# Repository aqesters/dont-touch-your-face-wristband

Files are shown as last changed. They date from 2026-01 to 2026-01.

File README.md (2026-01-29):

# dont-touch-your-face-wristband
A wristband that vibrates when the wearer tries to touch their face

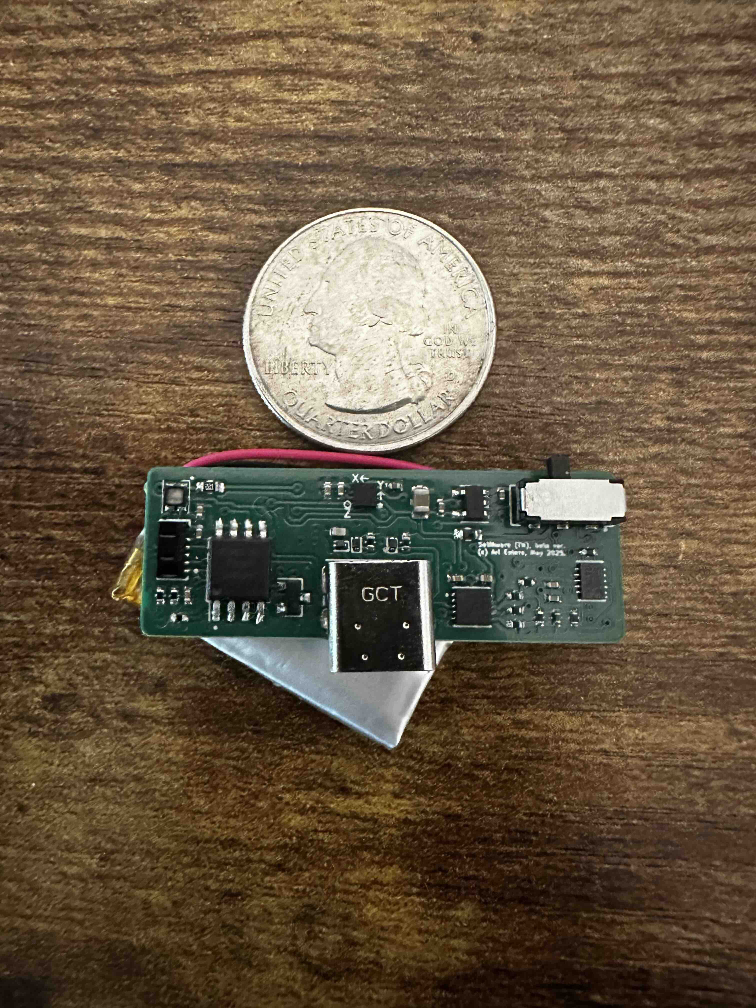
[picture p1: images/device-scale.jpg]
Assembled device


## System overview
First of all, the device must be worn on the inside of the wrist, facing towards the body when one's arm is by their side. 

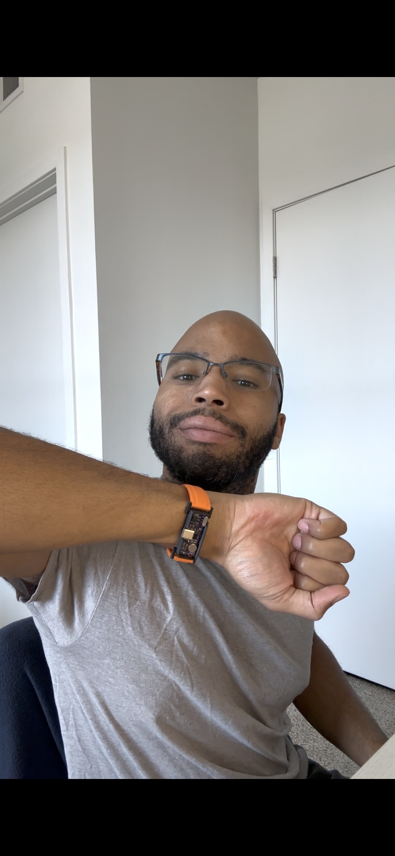
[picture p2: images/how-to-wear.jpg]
How to wear


The wristband functions by using two sensors: an accelerometer to measure arm position, and an IR optical sensor to measure proximity. The workflow is described below.
- The microcontroller remains in Sleep mode to conserve power until the arm is raised.
- Once the arm is raised - which is determined by an accelerometer threshold - the accelerometer wakes the microcontroller (MCU) via pin interrupt.
- The MCU remains in Active mode while the arm is raised. In Active mode, the MCU continuously polls the proximity sensor.
- If the proximity reading surpasses a certain threshold, the MCU triggers the vibration motor to alert the wearer.

Note that an alert will not be sent to the wearer unless both the arm is raised (accelerometer threshold) and the hand is close to the face (proximity threshold). This increases the likelihood that the wearer receives a vibration alert only if their hand is near their neck face.

## Cover glass for proximity sensor
In the assembly, the proximity sensor is purposely placed near the edge of the board. At this position, the sensor can detect proximity both above and beside the PCB. If using a cover glass, the following conditions must be met for best performance:
1. The cover glass must be made of IR-transparent material
2. The proximity sensor threshold may need to be increased, as cover glass will reflect some IR back to the sensor 
3. The cover glass should be curved such that the proximity sensor is sensitive to detection both above and near the edge of the PCB (see example)

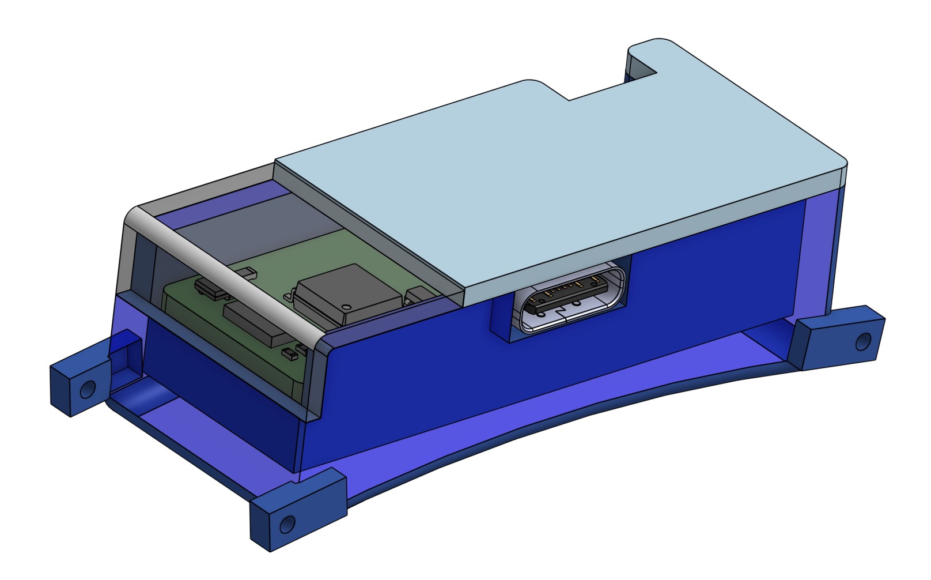
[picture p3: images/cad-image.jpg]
3D CAD rendering of assembled device


Note that this implementation for proximity sensing is **PATENT PENDING**.

## Enclosure
The enclosure has been designed to be 3D-printable using PLA and a 0.2 mm nozzle. The design is compatible with off-the-shelf 18 mm wrist straps (see link).

[Amazon link to wrist straps](https://www.amazon.com/dp/B0C1RQ1HML)

The enclosure consists of a "bottom" (which the PCB sits in) and a "lid" (which is glued to the "bottom" to cover the PCB). The enclosure was designed using Onshape. The STEP files are included in `enclosure/`, and the Onshape design file can be accessed at the link below.

[Link to Onshape CAD file](https://cad.onshape.com/documents/f453aeea43687b5a9c082ca3/w/8d4d5c0042ac79ddd7b31543/e/8a52f216663301647b5c429d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)

## Electronics
The Kicad design files, Gerber files, component datasheets, and bill of materials (BOM) are included in `electronics/`. The BOM includes components that can be assembled onto the board by PCB manufacturers. Not included in the BOM are the lithium polymer battery and the vibration motor. Links for those are provided below.

### Battery
The battery used in the initial version is a lithium polymer battery with a capacity of 110 mAh and dimensions of 28mm x 12mm x 4mm. The battery leads must be soldered to pads on the PCB.

The link points to a battery from LiPol battery, product number LP401228. Note that this is a foreign provider, and foreign shipping can be expensive. *It might be possible to find a **more convenient** LiPo battery vendor that can provide batteries with similar dimensions.*

[LiPo battery link](https://www.lithium-polymer-battery.net/8mah-200mah-3-7v-lithium-polymer-battery/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)

### Vibration motor
The motor used in the initial version is a brushed DC haptic motor from Vybronics. These can be purchased from Digikey. The motor leads must be soldered to pads on the PCB.

[Vibration motor link](https://www.digikey.com/en/products/detail/vybronics-inc/VCLP0820B004L/10285889)

## Firmware
The initial version uses an ATtiny85 microcontroller, and the firmware is written and compiled using the Arduino IDE with AtTinyCore board configuration. The Arduino file can be found in `firmware/`.

There are custom drivers for the IR proximity sensor and the battery gauge (present on board, but not yet used by firmware). These drivers are required by the MCU firmware to communicate with these components. These can be found in `firmware/libraries/` and must be included in the Arduino libraries path on the machine compiling the firmware (typical path is `~/Arduino/libraries`).

## Known issues
### No easy way to upload firmware
In-system programming (ISP) is not trivial for the ATtiny85 MCU due to the limited number of pins. The pins used for ISP are also used for I2C communication by the MCU. This is a limitation of the MCU itself, which is limited in its number of pins and features.

----- Potential solution -----

Implement BOTH of the following:
- Add series resistors (470 Ohms) on the PB0 and PB2 pins of the MCU.
- Add pads shorted to MCU Pins *VCC*, *GND*, *PB0*, *PB1*, *PB2*, and *PB5* to the board layout. These pads can be used in an ISP layout to re-program the MCU in place.

### IR proximity sensor VCNL4020 is at End-Of-Life
Vishay Semiconductor no longer sells the VCNL4020 sensor included in this design. However, the VCNL4030X1 is supported and is very similar, though it uses a different footprint.

----- Potential solution -----

Replace VCNL4020 sensor with VCNL4030X1 sensor. Replace the VCNL4020 part with the VCNL4030X1 part in the Kicad schematic and layout (symbol and footprint files already included). Create a driver for VCNL4030X1 using the VCNL4020 driver (in `firmware/libraries/`) as a starting point. 

### Unclear assembly directions for entire part 
The assembly instructions could be clearer, including the best order of operations (e.g., first cut wires to this length for battery and motor, then solder motor, then solder battery, etc...). I will try to expand on assembly instructions in the future. In the meantime, feel free to reach out to me with any questions.

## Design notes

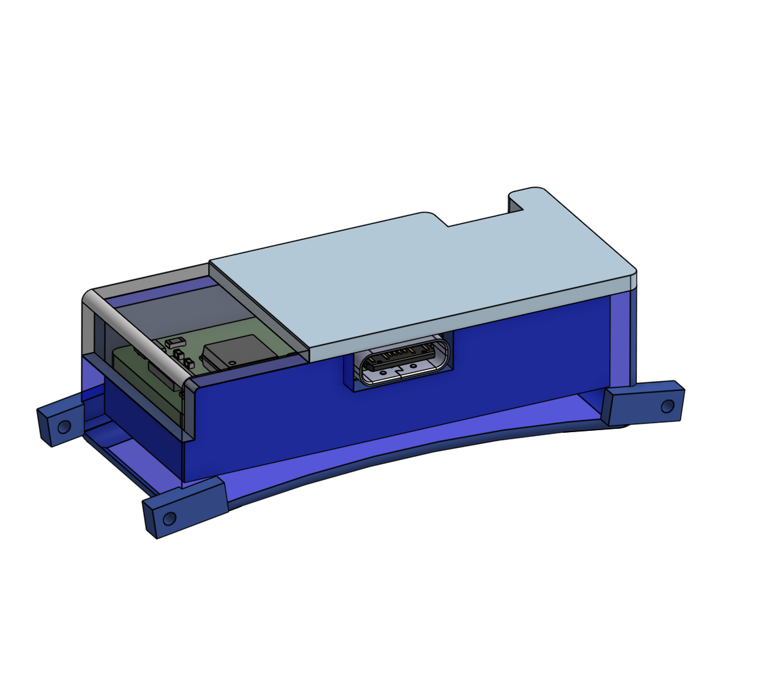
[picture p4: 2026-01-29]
images/cad-image-square.jpg

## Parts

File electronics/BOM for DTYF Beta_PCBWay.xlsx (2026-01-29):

 |  |  | Bill of Materials for DTYF Beta
Item # | *Designator | *Qty | Manufacturer | *Mfg Part # | Description / Value | *Package/Footprint | Type | Your Instructions / Notes
1 | C1, C3, C5, C6, C7, C8, C10, C11, C12 | 9 | Samsung Electro-Mechanics | CL05B104KP5NNNC | Unpolarized capacitor 100nF | 0402 | SMD
2 | C2, | 1 | Samsung Electro-Mechanics | CL05B224KO5NNNC | Unpolarized capacitor 220nF | 0402 | SMD
3 | C4, | 1 | Samsung Electro-Mechanics | CL05A105KO5NNNC | Unpolarized capacitor 1uF | 0402 | SMD
4 | C9, | 1 | Samsung Electro-Mechanics | CL05A475KQ5NRNC | Unpolarized capacitor 4.7 uF | 0402 | SMD
5 | C13, | 1 | Samsung Electro-Mechanics | CL05A106MQ5NUNC | Unpolarized capacitor 10uF | 0402 | SMD
6 | C14, | 1 | Samsung Electro-Mechanics | CL21A476MQYNNNE | Unpolarized capacitor 47 uF | 0805 | SMD
7 | D1, | 1 | Cree LED | CLMVC-FKA-CL1D1L71BB7C3C3 | RGB LED, anode/blue/green/red | PLCC4_2X2mm_CW | SMD | Pad 1 marked on PCB layout
8 | D2, | 1 | onsemi | ESD9B5.0ST5G | ESD protection diode, 5.0Vrwm | SOD-923 | SMD
9 | D3, D4, | 2 | onsemi | ESD9B3.3ST5G | ESD protection diode, 3.3Vrwm | SOD-923 | SMD
10 | J1, | 1 | GCT | USB4085-GF-A | USB-C receptacle connector USB4085 | GCT-USB4085 | Thru-hole
11 | J2, J3, | 2 | - | - | Custom SMD pads for customer use | - | DNI | DNI - No parts specified
12 | Q1, | 1 | onsemi | 2N7002 | 0.115A Id, 60V Vds, N-Channel MOSFET | SOT-23 | SMD
13 | R1, | 1 | YAGEO | RC0603FR-07220RL | Resistor 220 Ohms | 0603 | SMD
14 | R2, | 1 | Panasonic Electronic Components | ERJ-2BWFR050X | Current sense resistor 50 mOhms, 1% tolerance | 0402 | SMD | If replaced, tolerance must be 1% max
15 | R3, | 1 | Panasonic Electronic Components | ERJ-2RKF1001X | Resistor 1k | 0402 | SMD
16 | R4, R12, | 2 | Panasonic Electronic Components | ERJ-2RKF1004X | Resistor 1M | 0402 | SMD
17 | R5, | 1 | Panasonic Electronic Components | ERJ-2RKF1303X | Resistor 130k | 0402 | SMD
18 | R6, | 1 | Panasonic Electronic Components | ERA-2AEB9090X | Resistor 909 | 0402 | SMD
19 | R7, R9, R10, | 3 | Panasonic Electronic Components | ERJ-2GEJ472X | Resistor 4.7k | 0402 | SMD
20 | R8, | 1 | Panasonic Electronic Components | ERJ-3EKF22R0V | Resistor 22 | 0603 | SMD
21 | R11, | 1 | Panasonic Electronic Components | ERJ-2GEJ223X | Resistor 22k | 0402 | SMD
22 | R13, R14, | 2 | Panasonic Electronic Components | ERJ-2GEJ512X | Resistor 5.1k | 0402 | SMD
23 | SW1, | 1 | C&K | JS102011JAQN | Switch, single pole double throw (SPDT) | SW_SPDT_CK-JS102011JAQN | SMD | Pad 1 marked on PCB layout
24 | TH1, | 1 | Murata Electronics | NCU15XH103F6SRC | NTC 10k, temperature-dependent resistor | 0402 | SMD
25 | U1, | 1 | STMicroelectronics | LSM303AGRTR | IMU, accelerometer + magnetometer | LGA-12 | SMD | Pad 1 marked on PCB layout
26 | U2, | 1 | STMicroelectronics | STC3115AIQT | IC battery monitor | DFN-10 | SMD | Pad 1 marked on PCB layout
27 | U3, | 1 | Vishay Semiconductor | VCNL4020-GS08 | Optical sensor, IR and ambient | VDFN-10 | SMD | Pad 1 marked on PCB layout
28 | U4, | 1 | Microchip Technology | MCP73834-CNI/MF | IC single-cell battery control | DFN-10 | SMD | Pad 1 marked on PCB layout
29 | U5, | 1 | Microchip Technology | ATTINY85-20SU | AtTiny85 MCU, 8kB Flash, 512B SRAM, 512B EEPROM | SOIC-8 | DNI | DNI - I will program and install
30 | U6, | 1 | Diodes Incorporated | AP2112K-3.3TRG1 | 3.3V / 600mA LDO regulator with enable pin | SOT-25 | SMD | Pad 1 marked on PCB layout
 |  | 44
Need a quick and accurante quote? Need an efficient production? Please read SMT Ordering Necessary Files & Info in 1 minute. Thank you very much!
Click for Instructions on How to Create a BOM (https://www.pcbway.com/blog/PCB_Assembly/How_to_Build_a_BOM__Bill_Of_Materials_.html)

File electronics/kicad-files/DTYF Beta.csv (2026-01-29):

Source: | /Users/aesters/KiCad/DTYF Beta/DTYF Beta.sch
Date: | Tuesday, May 13, 2025 at 10:02:07 AM
Tool: | Eeschema (5.1.9-0-10_14)
Generator: | /private/var/folders/29/kllrrlc97vqc5shptfvqt_yr0000gn/T/AppTranslocation/2EDB60D3-1D7B-4026-A727-D76486822BE3/d/kicad.app/Contents/SharedSupport/plugins/bom_csv_grouped_by_value_with_fp.py
Component Count: | 44
Ref | Qnty | Value | Cmp name | Footprint | Description | Vendor
C1, C3, C5, C6, C7, C8, C10, C11, C12, | 9 | 100n | C | Capacitor_SMD:C_0402_1005Metric | Unpolarized capacitor
C2, | 1 | 220n | C | Capacitor_SMD:C_0402_1005Metric | Unpolarized capacitor
C4, | 1 | 1u | C | Capacitor_SMD:C_0402_1005Metric | Unpolarized capacitor
C9, | 1 | 4.7u | C | Capacitor_SMD:C_0402_1005Metric | Unpolarized capacitor
C13, | 1 | 10u | C | Capacitor_SMD:C_0402_1005Metric | Unpolarized capacitor
C14, | 1 | 47u | C | Capacitor_SMD:C_0805_2012Metric | Unpolarized capacitor
D1, | 1 | LED_ABGR | LED_ABGR | LED_SMD:LED_Cree-PLCC4_2x2mm_CW | RGB LED, anode/blue/green/red
D2, | 1 | ESD9B5.0ST5G | ESD9B5.0ST5G | Diode_SMD:D_SOD-923 | ESD protection diode, 5.0Vrwm, SOD-923
D3, D4, | 2 | ESD9B3.3ST5G | ESD9B3.3ST5G | Diode_SMD:D_SOD-923 | ESD protection diode, 3.3Vrwm, SOD-923
J1, | 1 | USB_C_Receptacle_GCT_USB4085 | USB_C_Receptacle_GCT_USB4085 | Connector_USB:USB_C_Receptacle_GCT_USB4085 | USB Full-Featured Type-C Receptacle connector
J2, J3, | 2 | Conn_01x02_Female | Conn_01x02_Female | 1_MyFootprints:SMD_Pads_X1_Y2_W3mm | Generic connector, single row, 01x02, script generated (kicad-library-utils/schlib/autogen/connector/)
Q1, | 1 | 2N7002 | 2N7002 | Package_TO_SOT_SMD:SOT-23 | 0.115A Id, 60V Vds, N-Channel MOSFET, SOT-23
R1, | 1 | 220 | R | Resistor_SMD:R_0603_1608Metric | Resistor
R2, | 1 | 50m | R | Resistor_SMD:R_0402_1005Metric | Resistor
R3, | 1 | 1k | R | Resistor_SMD:R_0402_1005Metric | Resistor
R4, R12, | 2 | 1M | R | Resistor_SMD:R_0402_1005Metric | Resistor
R5, | 1 | 130k | R | Resistor_SMD:R_0402_1005Metric | Resistor
R6, | 1 | 909 | R | Resistor_SMD:R_0402_1005Metric | Resistor
R7, R9, R10, | 3 | 4.7k | R | Resistor_SMD:R_0402_1005Metric | Resistor
R8, | 1 | 22 | R | Resistor_SMD:R_0603_1608Metric | Resistor
R11, | 1 | 22k | R | Resistor_SMD:R_0402_1005Metric | Resistor
R13, R14, | 2 | 5.1k | R | Resistor_SMD:R_0402_1005Metric | Resistor
SW1, | 1 | SW_SPDT | SW_SPDT | Button_Switch_SMD:SW_SPDT_CK-JS102011JAQN | Switch, single pole double throw
TH1, | 1 | 10k therm | Thermistor | Resistor_SMD:R_0402_1005Metric | Temperature dependent resistor
U1, | 1 | LSM303AGR | LSM303AGR-LSM303AGR | 1_MyFootprints:LSM303AGR
U2, | 1 | STC3115AIQT | STC3115AIQT | 1_MyFootprints:STC3115AIQT
U3, | 1 | VCNL4020-GS08 | VCNL4020-GS08-VCNL_Vishay | 1_MyFootprints:VCNL4020-GS08
U4, | 1 | MCP73834 | MCP73834 | 1_MyFootprints:MCP73834-CNI&slash_MF
U5, | 1 | ATtiny85-20SU | ATtiny85-20SU | Package_SO:SOIC-8_5.275x5.275mm_P1.27mm | 20MHz, 8kB Flash, 512B SRAM, 512B EEPROM, debugWIRE, SOIJ-8
U6, | 1 | AP2112K-3.3 | AP2112K-3.3 | Package_TO_SOT_SMD:SOT-23-5 | 600mA low dropout linear regulator, with enable pin, 3.8V-6V input voltage range, 3.3V fixed positive output, SOT-23-5

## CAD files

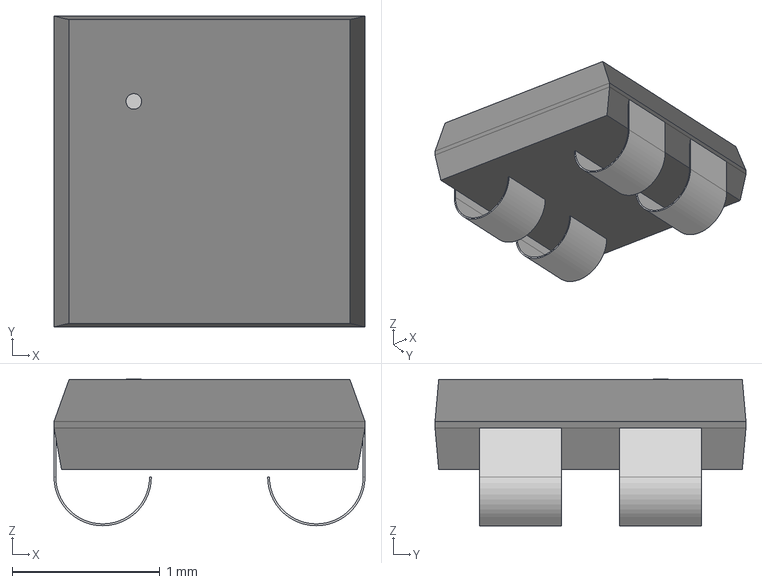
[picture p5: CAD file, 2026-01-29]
electronics/kicad-files/3D Files/RGB LED_CLMVC-FKA-CL1D1L71BB7C3C3.step
2.11 x 2.11 x 0.993 mm

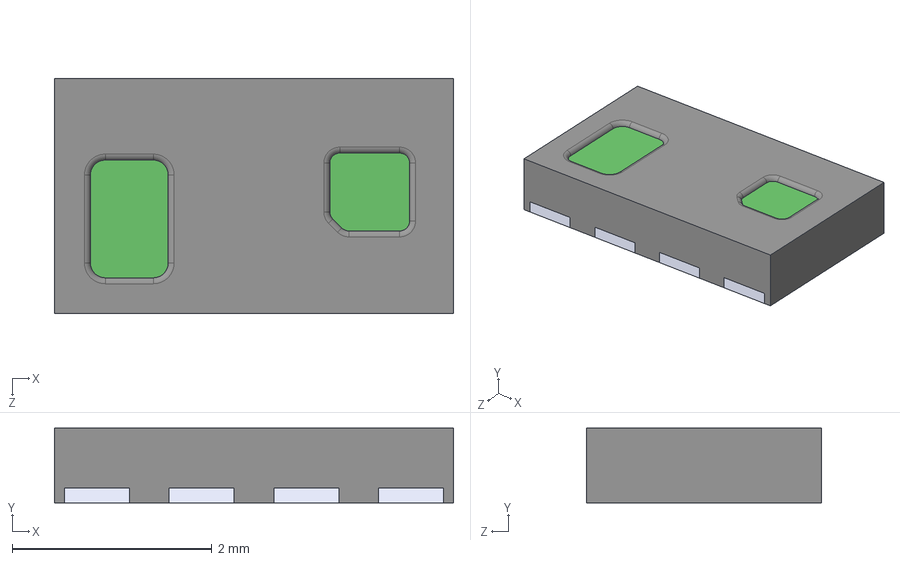
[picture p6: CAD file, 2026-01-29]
electronics/kicad-files/VCNL4030X01-GS08.step
4.00 x 0.75 x 2.36 mm

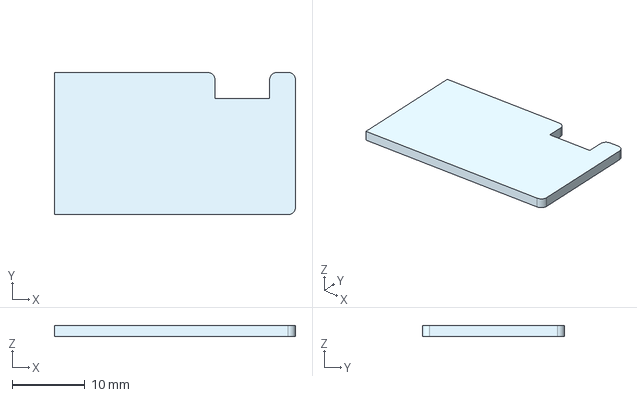
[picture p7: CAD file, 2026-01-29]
enclosure/DTYF Beta - Housing lid.step
33.1 x 19.5 x 1.50 mm

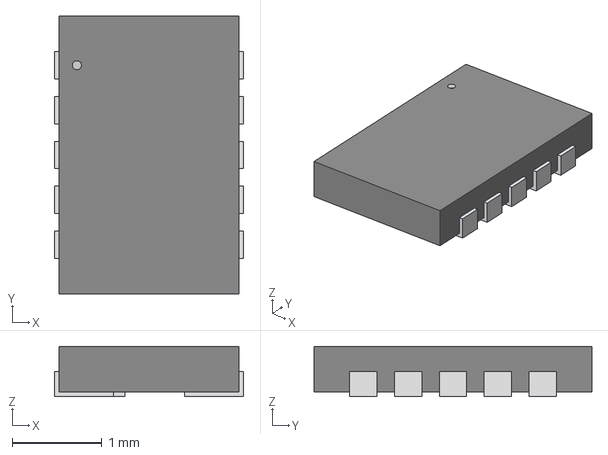
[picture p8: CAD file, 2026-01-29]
electronics/kicad-files/3D Files/STC3115AIQT.step
2.11 x 3.10 x 0.561 mm

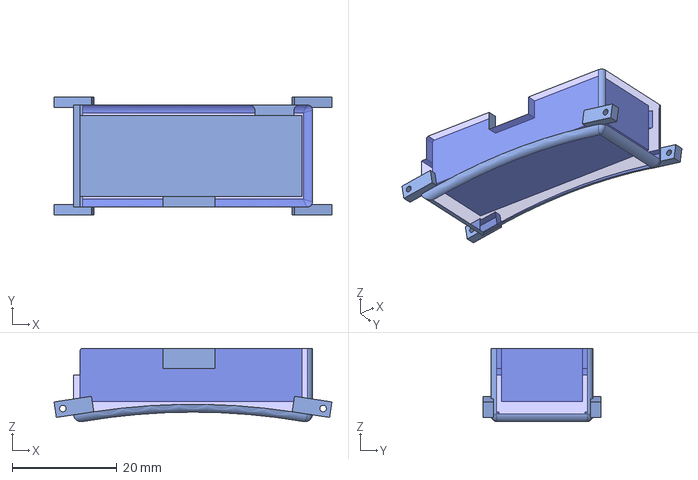
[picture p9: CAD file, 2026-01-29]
enclosure/DTYF Beta - Housing bottom 20250906.step
53.2 x 22.5 x 14.0 mm

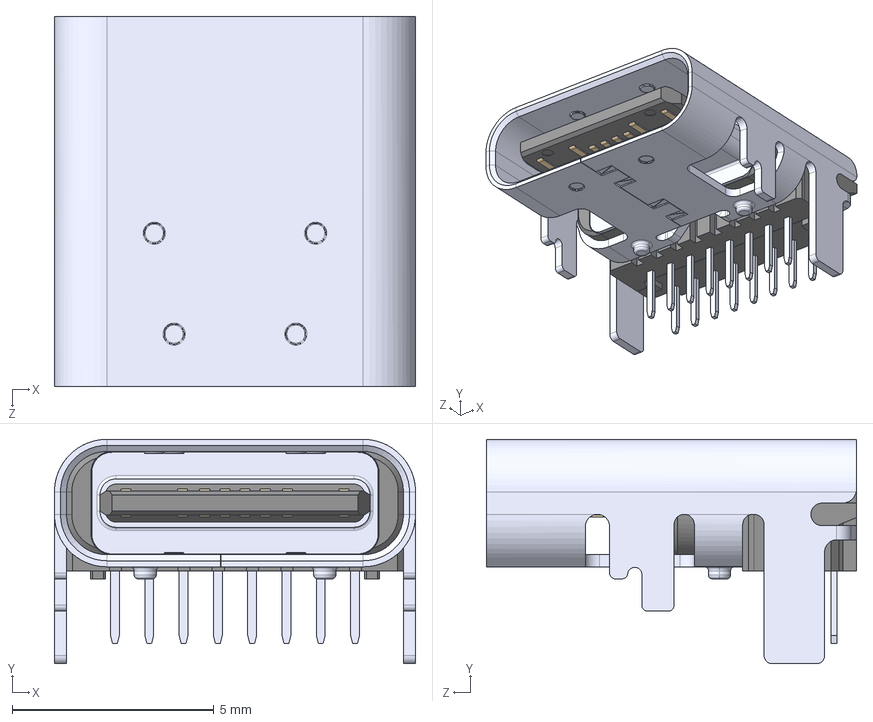
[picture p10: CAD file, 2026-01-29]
electronics/kicad-files/3D Files/USB4085-GF-A.step
8.95 x 5.56 x 9.17 mm

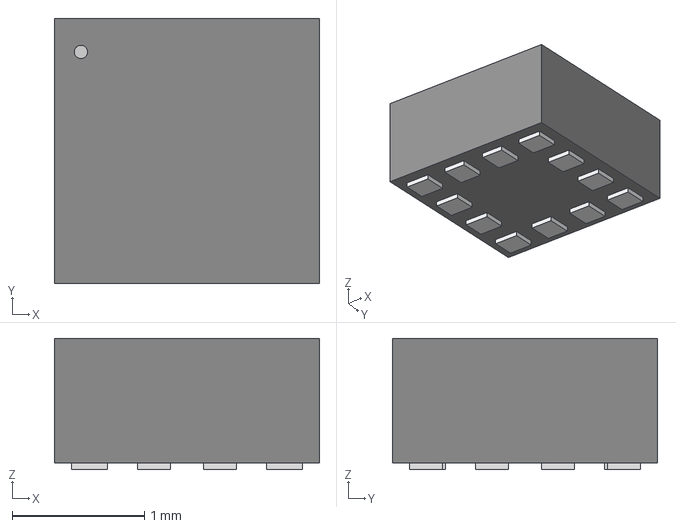
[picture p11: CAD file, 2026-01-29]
electronics/kicad-files/3D Files/LSM303AGRTR.step
2.01 x 2.01 x 0.993 mm

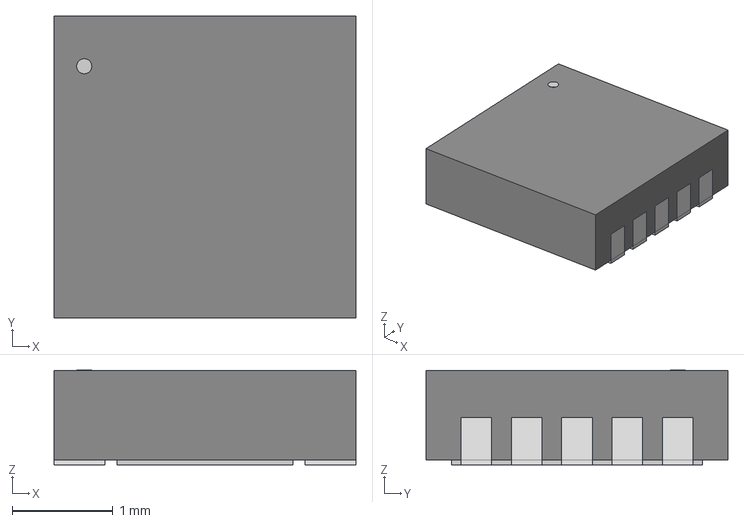
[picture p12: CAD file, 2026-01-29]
electronics/kicad-files/3D Files/MCP73834_CNI_MF.step
3.00 x 3.00 x 0.942 mm

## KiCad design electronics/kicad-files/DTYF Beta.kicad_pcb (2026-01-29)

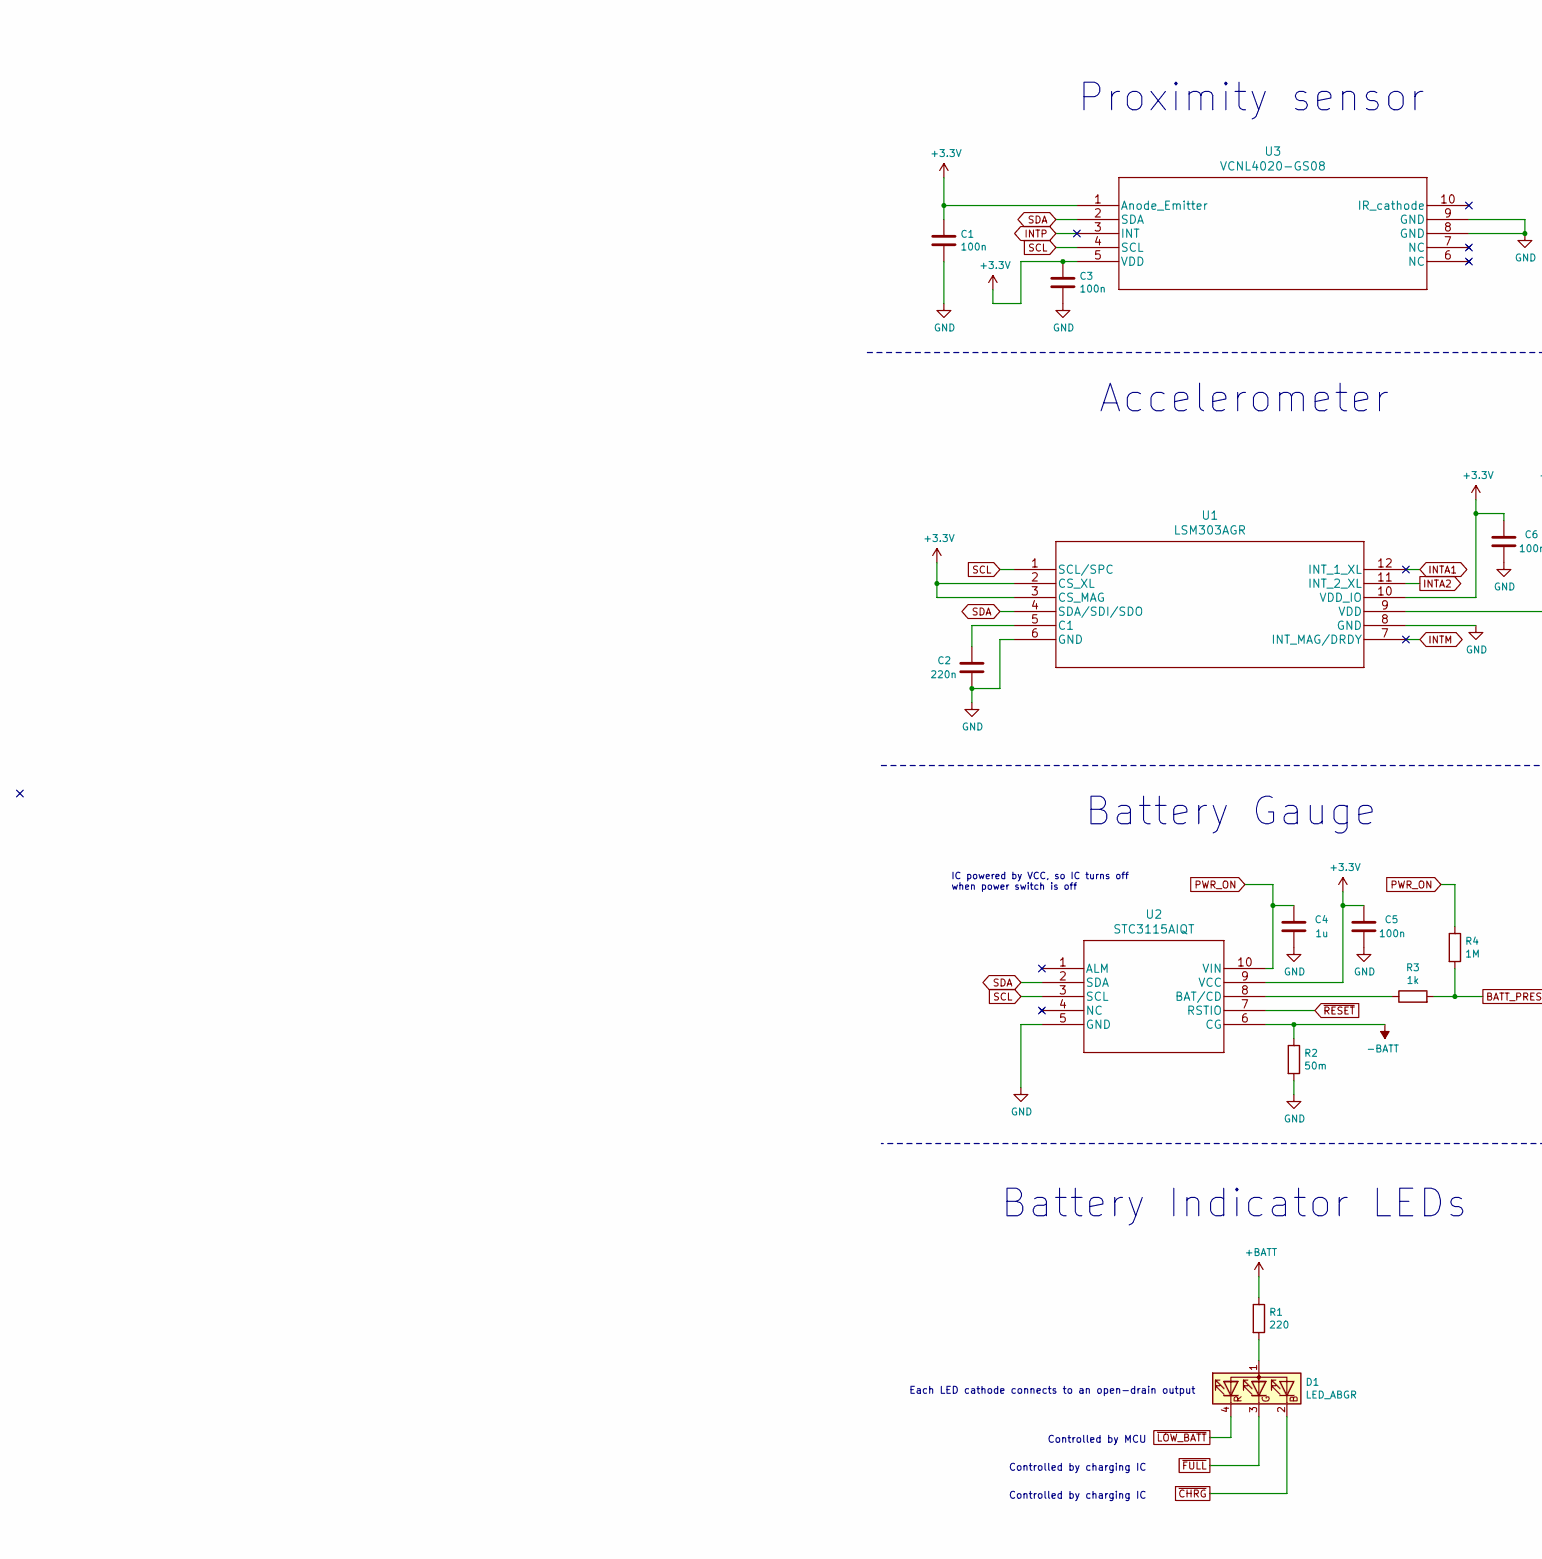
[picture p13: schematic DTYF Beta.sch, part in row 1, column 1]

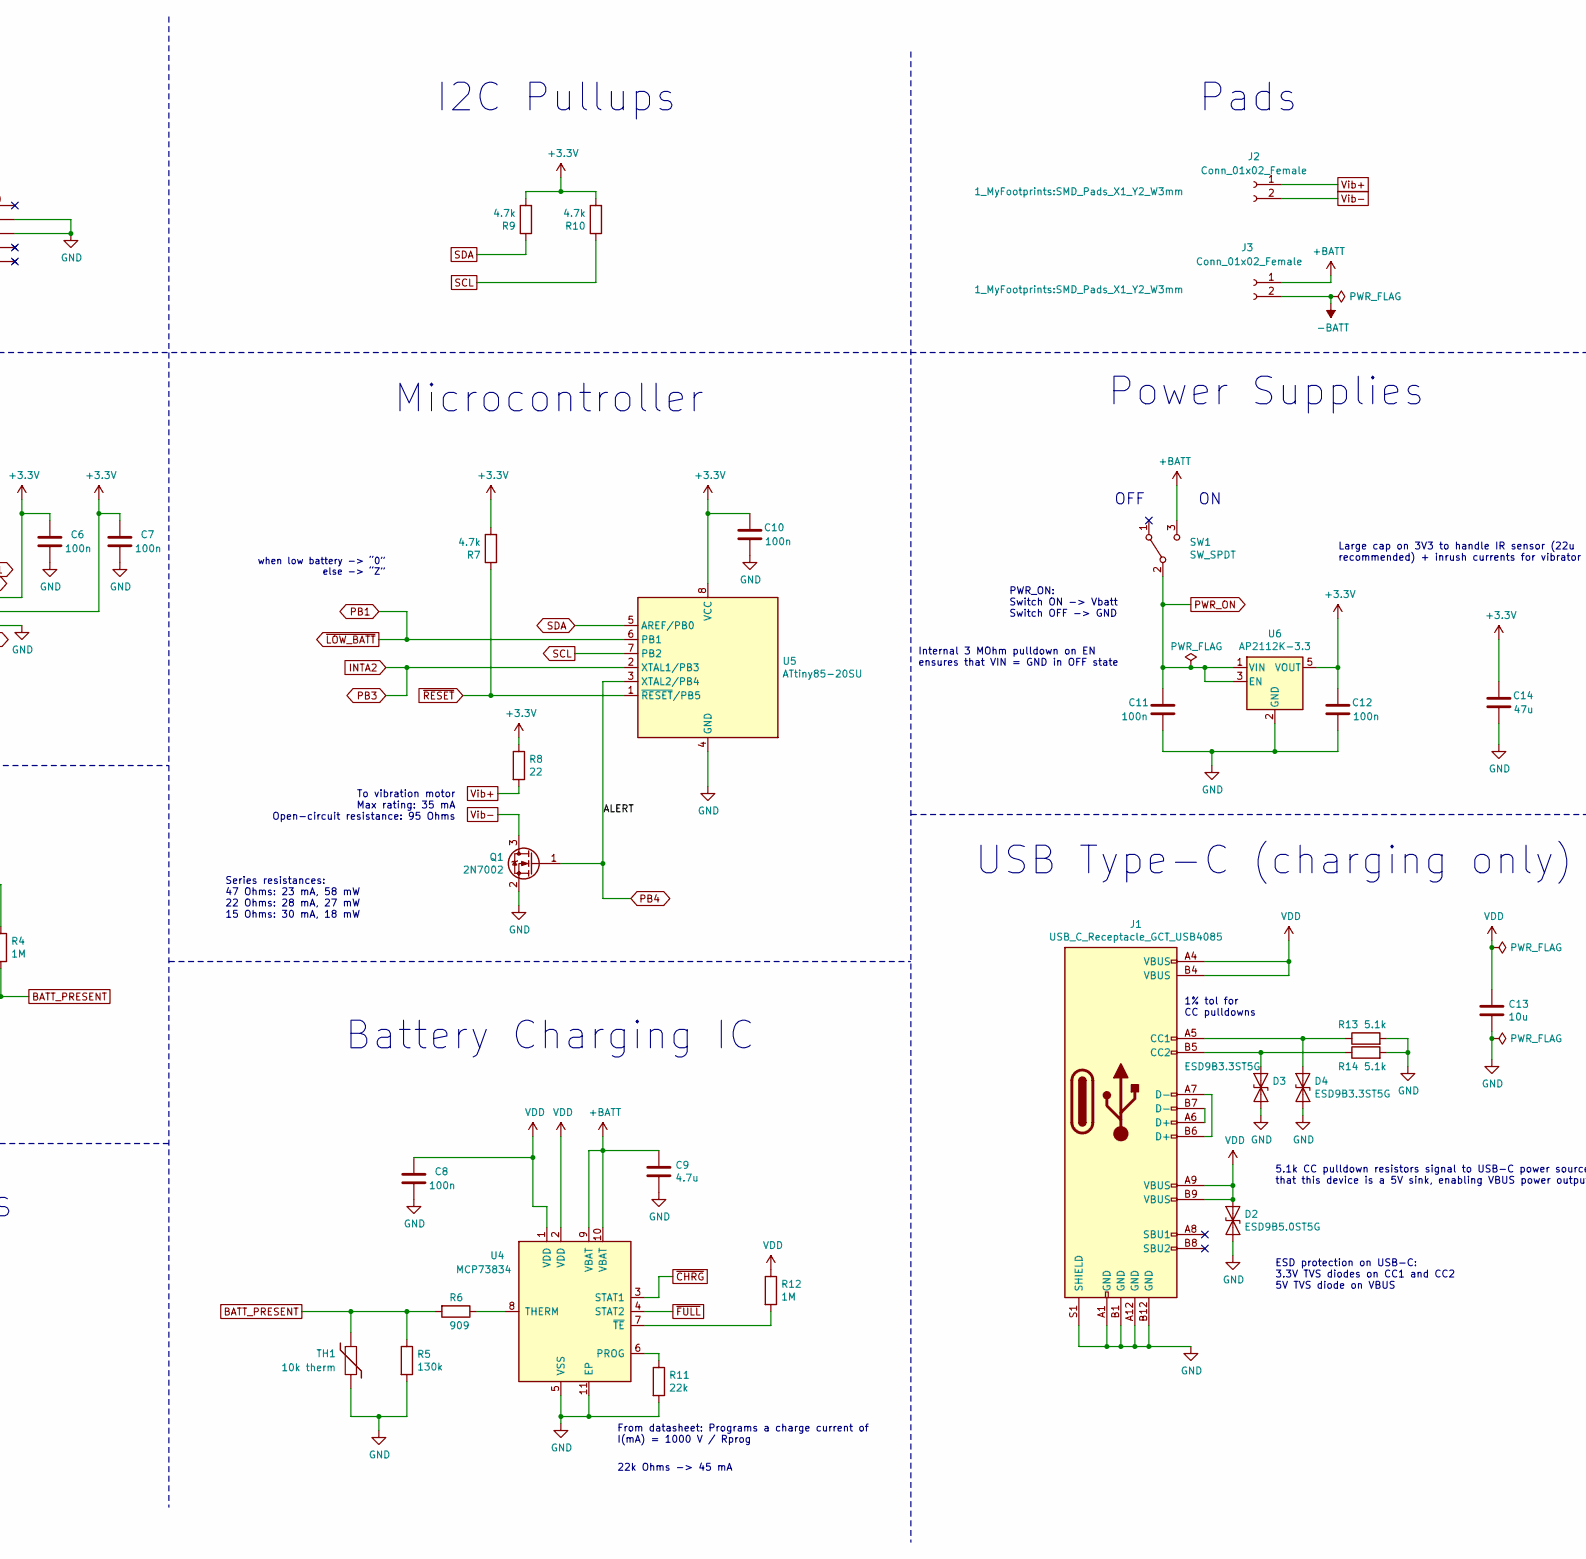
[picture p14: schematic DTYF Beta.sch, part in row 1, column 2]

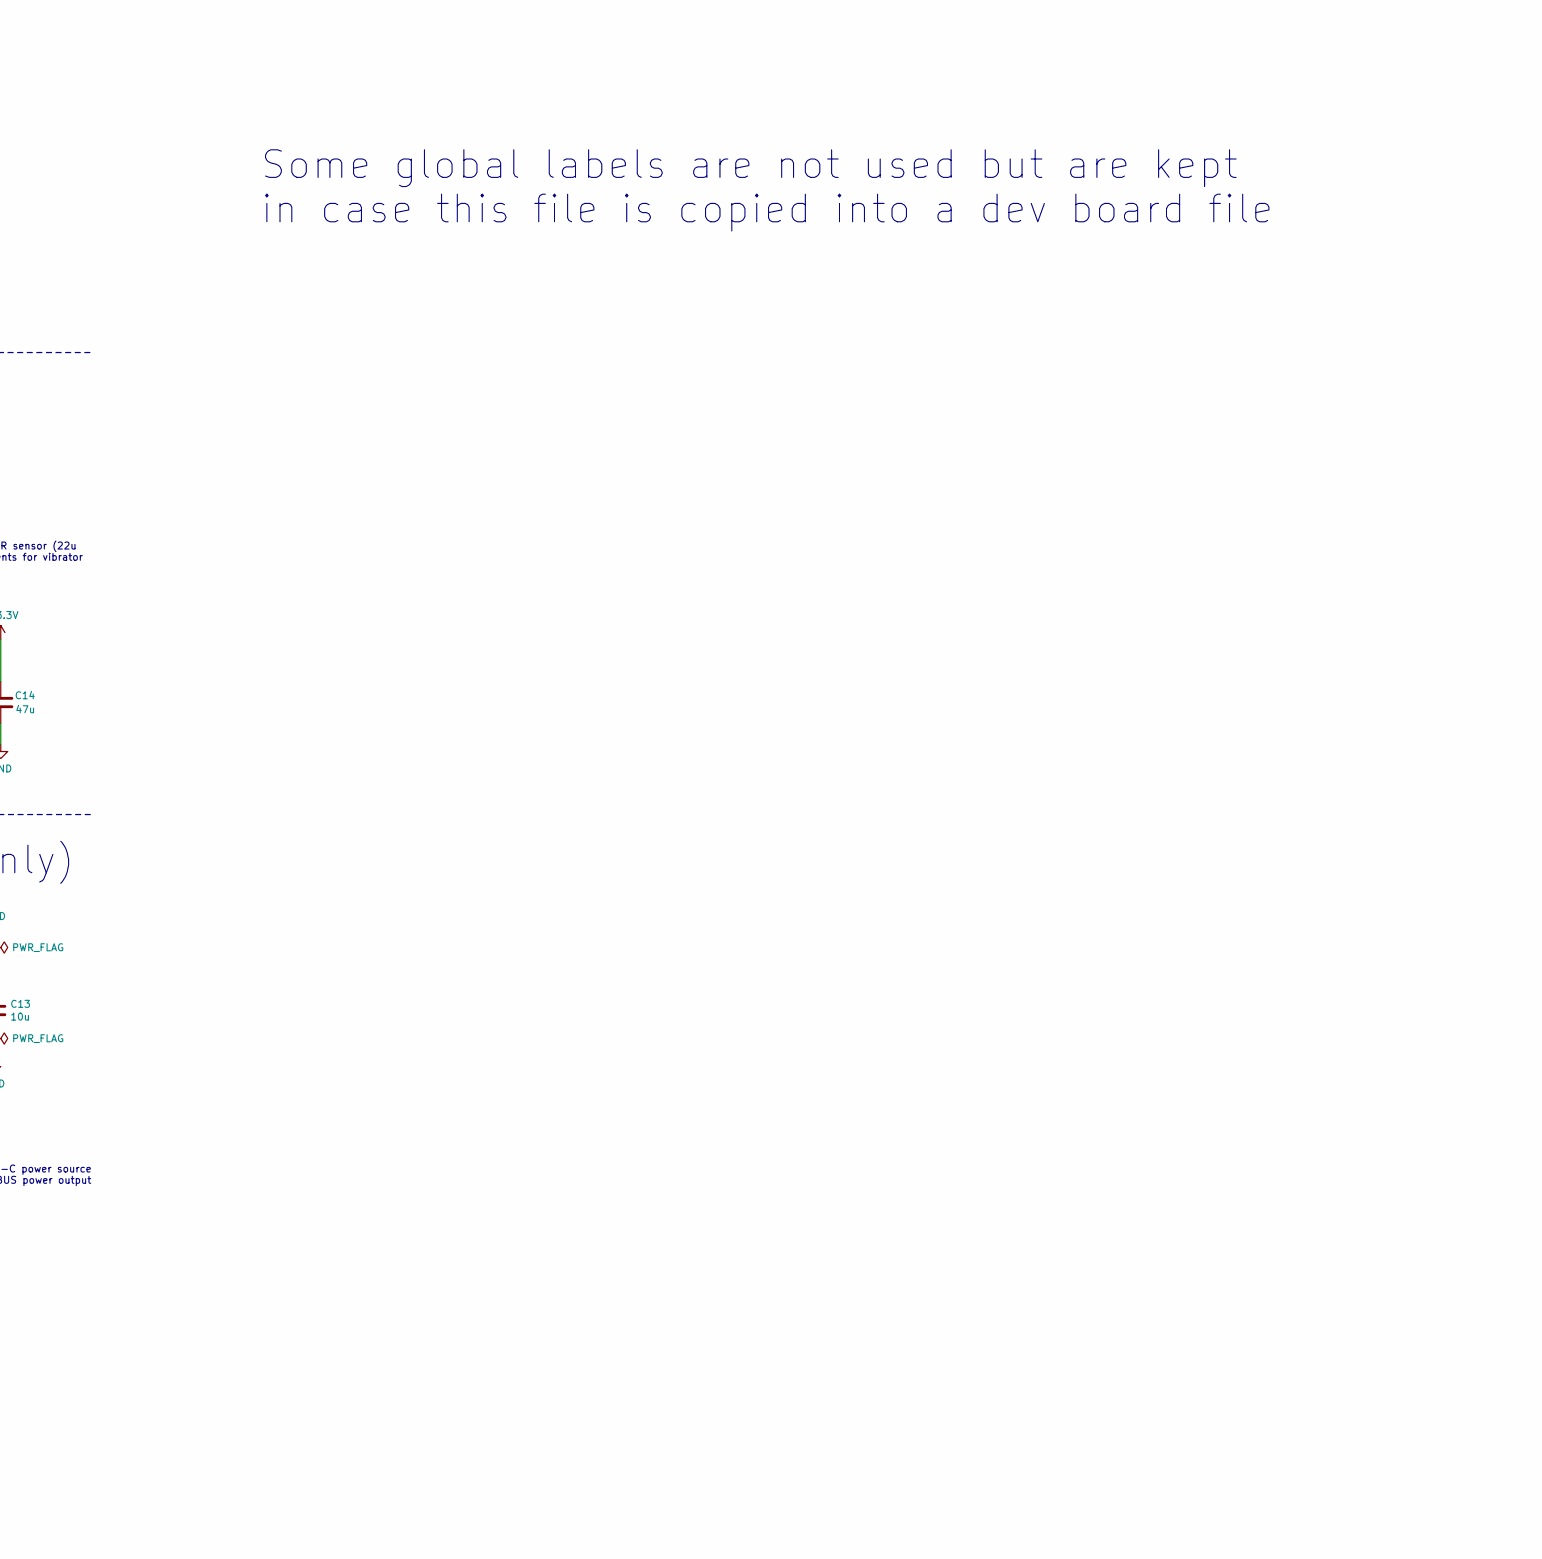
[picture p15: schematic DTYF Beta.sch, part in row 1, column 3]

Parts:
C1, C3, C5, C6, C7, C8, C10, C11, C12: 100n; C_0402_1005Metric
C2: 220n; C_0402_1005Metric
C4: 1u; C_0402_1005Metric
C9: 4.7u; C_0402_1005Metric
C13: 10u; C_0402_1005Metric
C14: 47u; C_0805_2012Metric
D1: LED_ABGR; LED_Cree-PLCC4_2x2mm_CW
D2: ESD9B5.0ST5G; D_SOD-923
D3, D4: ESD9B3.3ST5G; D_SOD-923
J1: USB_C_Receptacle_GCT_USB4085
J2, J3: Conn_01x02_Female; SMD_Pads_X1_Y2_W3mm
Q1: 2N7002; SOT-23
R1: 220; R_0603_1608Metric
R2: 50m; R_0402_1005Metric
R3: 1k; R_0402_1005Metric
R4, R12: 1M; R_0402_1005Metric
R5: 130k; R_0402_1005Metric
R6: 909; R_0402_1005Metric
R7, R9, R10: 4.7k; R_0402_1005Metric
R8: 22; R_0603_1608Metric
R11: 22k; R_0402_1005Metric
R13, R14: 5.1k; R_0402_1005Metric
SW1: SW_SPDT; SW_SPDT_CK-JS102011JAQN
TH1: 10k therm; R_0402_1005Metric
U1: LSM303AGR
U2: STC3115AIQT
U3: VCNL4020-GS08
U4: MCP73834; MCP73834-CNI&slash_MF
U5: ATtiny85-20SU; SOIC-8_5.275x5.275mm_P1.27mm
U6: AP2112K-3.3; SOT-23-5

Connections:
+3V3: C1.1, C3.1, C5.1, C6.1, C7.1, C10.1, C12.1, C14.1, R7.2, R8.1, R9.2, R10.2, U1.2 (CS_XL), U1.3 (CS_MAG), U1.9 (VDD), U1.10 (VDD_IO), U2.9 (VCC), U3.1 (Anode_Emitter), U3.5 (VDD), U5.8 (VCC), U6.5 (VOUT)
+BATT: C9.1, J3.1, R1.1, SW1.3 (C), U4.9 (VBAT), U4.10 (VBAT)
-BATT: J3.2, R2.1, U2.6 (CG)
BATT_PRESENT: R3.2, R4.2, R5.1, R6.2, TH1.1
GND: C1.2, C2.2, C3.2, C4.2, C5.2, C6.2, C7.2, C8.2, C9.2, C10.2, C11.2, C12.2, C13.2, C14.2, D2.2 (A2), D3.2 (A2), D4.2 (A2), J1.A1 (GND), J1.A12 (GND), J1.B1 (GND), J1.B12 (GND), J1.S1 (SHIELD), Q1.2 (S), R2.2, R5.2, R11.2, R13.2, R14.2, TH1.2, U1.6 (GND), U1.8 (GND), U2.5 (GND), U3.8 (GND), U3.9 (GND), U4.5 (VSS), U4.11 (EP), U5.4 (GND), U6.2 (GND)
INTA1: U1.12 (INT_1_XL)
INTA2: U1.11 (INT_2_XL), U5.2 (XTAL1/PB3)
INTM: U1.7 (INT_MAG/DRDY)
INTP: U3.3 (INT)
unnamed: C2.1, U1.5 (C1)
unnamed: D1.1 (A), R1.2
unnamed: D3.1 (A1), J1.B5 (CC2), R14.1
unnamed: D4.1 (A1), J1.A5 (CC1), R13.1
unnamed: J1.A6 (D+), J1.B7 (D-)
unnamed: J1.A7 (D-), J1.B6 (D+)
unnamed: R3.1, U2.8 (BAT/CD)
unnamed: R6.1, U4.8 (THERM)
unnamed: R11.1, U4.6 (PROG)
unnamed: R12.2, U4.7 (~TE)
PB1: D1.4 (RK), U5.6 (PB1)
PB4: Q1.1 (G), U5.3 (XTAL2/PB4)
PWR_ON: C4.1, C11.1, R4.1, SW1.2 (B), U2.10 (VIN), U6.1 (VIN), U6.3 (EN)
SCL: R10.1, U1.1 (SCL/SPC), U2.3 (SCL), U3.4 (SCL), U5.7 (PB2)
SDA: R9.1, U1.4 (SDA/SDI/SDO), U2.2 (SDA), U3.2 (SDA), U5.5 (AREF/PB0)
VDD: C8.1, C13.1, D2.1 (A1), J1.A4 (VBUS), J1.A9 (VBUS), J1.B4 (VBUS), J1.B9 (VBUS), R12.1, U4.1 (VDD), U4.2 (VDD)
Vib+: J2.1, R8.2
Vib-: J2.2, Q1.3 (D)
~CHRG: D1.2 (BK), U4.3 (STAT1)
~FULL: D1.3 (GK), U4.4 (STAT2)
~RESET: R7.1, U2.7 (RSTIO), U5.1 (~RESET~/PB5)

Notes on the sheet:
Microcontroller
Series resistances: 47 Ohms: 23 mA, 58 mW 22 Ohms: 28 mA, 27 mW 15 Ohms: 30 mA, 18 mW
Accelerometer
Pads
Battery Indicator LEDs
Power Supplies
Battery Charging IC
Battery Gauge
I2C Pullups
From datasheet: Programs a charge current of I(mA) = 1000 V / Rprog
To vibration motor Max rating: 35 mA Open-circuit resistance: 95 Ohms
USB Type-C (charging only)
22k Ohms -> 45 mA
when low battery -> “0” else -> “Z”
Each LED cathode connects to an open-drain output
1% tol for CC pulldowns
5.1k CC pulldown resistors signal to USB-C power source that this device is a 5V sink, enabling VBUS power output
Controlled by MCU
IC powered by VCC, so IC turns off when power switch is off
Proximity sensor
OFF
PWR_ON: Switch ON -> Vbatt Switch OFF -> GND
Some global labels are not used but are kept in case this file is copied into a dev board file
Controlled by charging IC
Internal 3 MOhm pulldown on EN ensures that VIN = GND in OFF state
Large cap on 3V3 to handle IR sensor (22u recommended) + inrush currents for vibrator
ESD protection on USB-C: 3.3V TVS diodes on CC1 and CC2 5V TVS diode on VBUS

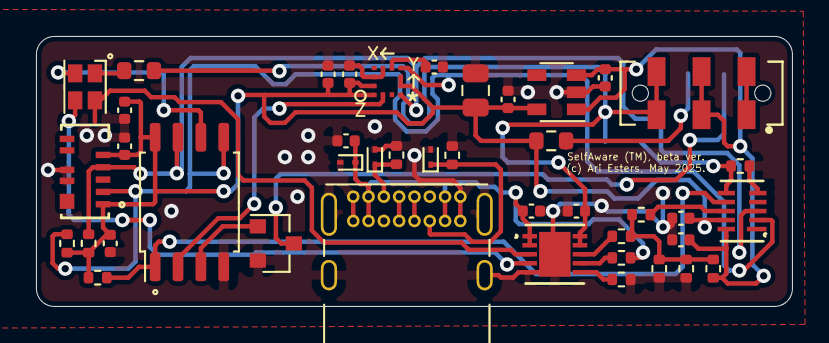
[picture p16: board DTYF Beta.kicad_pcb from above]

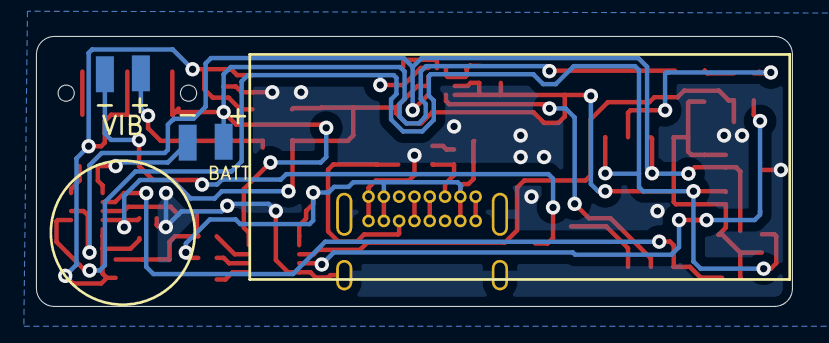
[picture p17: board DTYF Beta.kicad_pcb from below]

Board: 2 copper layers, 42.0 x 15.0 mm, 44 parts (2 on the bottom side), 27 nets.

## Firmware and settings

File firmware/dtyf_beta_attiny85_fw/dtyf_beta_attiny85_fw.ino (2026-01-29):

#include <Wire.h>
#include <avr/sleep.h>
#include <avr/interrupt.h>
#include <avr/wdt.h>
//#include <STC3115.h>  // battery gauge - NOT USED IN THIS VERSION
#include <VCNL4020.h>

// Sensor inputs and thresholds
const uint8_t period = 200;                   // sampling period while awake, in ms
const float accel_threshold = 6.9;            // m/s^2, corresponds to 45 deg from vertical
const uint8_t led_current = 150;              // set between 0 and 200 mA (in increments of 10)
uint16_t prox_threshold = 0;                  // post-calibration threshold for proximity sensor

// For VCNL4020 calibration
bool do_calib = false;                        // determines whether proximity calibration is done
const uint16_t pthresh_with_calib = 1000;     // if do_calib == true
const uint16_t pthresh_no_calib = 4000;       // if do_calib == false

// Initialize variables
float accel = 0.0;
uint16_t prox = 0;
uint8_t n_calib_samples = 10;   // for proximity sensor calibration
unsigned long sum = 0;          // for proximity sensor calibration
uint16_t background = 0;        // for proximity sensor calibration
volatile bool int_triggered = false;

// Define pins
const int INT_PIN = 3;        // Triggered by accelerometer (PB3 / Attiny Pin 2)
const int ALERT_PIN = 4;      // LED indicating alert to user (PB4 / Attiny Pin 3)

// Device I2C addresses
#define ADDR_ACCEL 0X19         // LSM303AGR
#define ADDR_MAG 0x1E           // LSM303AGR

// Magnetometer registers
#define CFG_REG_A_M 0x60    // Magnetometer config

// Accelerometer registers
#define CTRL_REG1_A 0x20    // Options: enable XYZ measurements, data sampling rate, low-power mode
#define CTRL_REG4_A 0x23    // Options: full-scale, self-test
#define CTRL_REG6_A 0x25    // Interrupt pin settings
#define INT2_CFG_A 0x34     // Interrupt 2 (INT2) setup
#define INT2_SRC_A 0x35     // Check INT2 status (unlatches when read if latch is enabled)
#define INT2_THS_A 0x36     // Set threshold for INT2 function
#define ACCEL_OUT_X 0x28    // X accelerometer output
#define ACCEL_OUT_Y 0x2A    // Y accelerometer output
#define ACCEL_OUT_Z 0x2C    // Z accelerometer output

// I2C read operation (max read: 2 bytes)
template <typename T>
T i2cRead(uint8_t deviceAddress, uint8_t startRegister, uint8_t numBytes, bool bigEndian = false) 
{ 
  uint16_t rawValue = 0;   // max: 2 bytes worth  

  // start I2C comms with device
  Wire.beginTransmission(deviceAddress);  

  // set target register for reading
  Wire.write(startRegister);
  Wire.endTransmission();

  // read contents from consecutive registers
  Wire.requestFrom(deviceAddress, numBytes); 
  for (int i = 0; i < numBytes; i++) {    
    uint8_t currentByte = Wire.read();
    if (bigEndian) {
      rawValue |= uint16_t (currentByte << 8*(numBytes - 1 - i));
    }
    else {
      rawValue |= uint16_t (currentByte << 8*i);
    }
    // device auto-increments register after each read
  }

  // return in specified format
  return static_cast<T>(rawValue);
}

// I2C write operation
void i2cWrite(uint8_t command, uint8_t deviceAddress, uint8_t startRegister, uint8_t numBytes, bool bigEndian = false) 
{ 
  // start I2C comms with device
  Wire.beginTransmission(deviceAddress);

  // write one byte to each consecutive register
  Wire.write(startRegister);      
  for (int i = 0; i < numBytes; i++) { 
    uint8_t currentByte;

    // start at MSB (big endian) or LSB (little endian)
    if (bigEndian) {
      currentByte = 0xFF & (command >> 8*(numBytes - 1 - i));
    }
    else {
      currentByte = 0xFF & (command >> 8*i);
    }
    Wire.write(currentByte);
    // device auto-increments register after each write
  }
  Wire.endTransmission();
}

// Define sensor objects
//STC3115 gauge(110, 50, 100);    // capacity, sense resistor, internal resistance
VCNL4020 prox_sensor;

void setup() {
  /// BOARD SETUP ///
  pinMode(ALERT_PIN, OUTPUT);
  pinMode(INT_PIN, INPUT_PULLUP);
  digitalWrite(ALERT_PIN, LOW);
  Wire.begin();  // initialize I2C
  delay(50);

  /// CONFIGURE ALL DEVICES ///
  setupSensors();     // accelerometer and IR sensor
  //gauge.startup();    // battery fuel gauge (USE IN FUTURE VERSIONS)

  /// SENSOR CALIBRATION ///
  if (do_calib) {
    background = proxCalibration(&prox_sensor);
    prox_threshold = pthresh_with_calib;
  } 
  else {
    background = 0;
    prox_threshold = pthresh_no_calib;
  }

  /// SET UP SLEEP/INTERRUPT LOGIC ///
  cli(); // Disable interrupts temporarily

  // Enable Pin Change Interrupt on PB3 (Pin 2 on ATtiny85)
  GIMSK |= (1 << PCIE);    // Enable Pin Change Interrupts
  PCMSK |= (1 << PCINT3); // Enable Pin Change Interrupt on PB3
  sleep_bod_disable(); // Disable brown-out detector

  sei(); // Re-enable interrupts
}

void loop() 
{
  // go back to sleep if interrupt is HIGH
  if (digitalRead(INT_PIN) == HIGH) { 
    //i2cWrite(1, ADDR_PROX, PROX_REG_00, 1);   // stop prox measurements
    digitalWrite(ALERT_PIN, LOW);
    goToSleep();
  }

  // check accel reading if interrupt is LOW
  else if (digitalRead(INT_PIN) == LOW) {
    accel = readAccelY();

    // arm is down -> not the signal we want 
    if (accel < 0) {  
      goToSleep();    
    }
    // arm is up -> get proximity measurements
    else {   
      // check if prox reading > threshold
      prox = VCNL4020_ReadProximity(&prox_sensor);
      prox = prox - background;
      if (prox > prox_threshold) {  
        digitalWrite(ALERT_PIN, HIGH);  // activate buzzer
      } else {
        digitalWrite(ALERT_PIN, LOW);   // deactivate buzzer
      }
      VCNL4020_ClearInterrupts(&prox_sensor);
      delay(period);
    }
  }
}

// Interrupt Service Routine for Pin Change Interrupt on Port D
ISR(PCINT0_vect) {
  int_triggered = true; 
}

/// FUNCTION LIST ///

// Configure sensors
void setupSensors() 
{
  // Disable magnetometer
  i2cWrite(0b11, ADDR_MAG, CFG_REG_A_M, 1);

  // Set up accelerometer
  i2cWrite(0b00100010, ADDR_ACCEL, CTRL_REG1_A, 1);   // normal mode, 10 Hz, enable Y-axis
  i2cWrite(0, ADDR_ACCEL, CTRL_REG4_A, 1);            // full scale = +/-2 g
  i2cWrite(0b00100010, ADDR_ACCEL, CTRL_REG6_A, 1);   // enable interrupt, active-low on INT2
  i2cWrite(1 << 3, ADDR_ACCEL, INT2_CFG_A, 1);        // INT2 activates when abs(y) > threshold
  i2cWrite(static_cast<uint8_t>(accel_threshold/9.8*1000/(2000./128)), ADDR_ACCEL, INT2_THS_A, 1);  // set threshold for interrupt
  // NOTE: ensure accelerometer runs 10 Hz max to allow start-up time during MCU wake-up

  // Set up proximity sensor
  VCNL4020_Init(&prox_sensor);
  VCNL4020_SetCurrent(&prox_sensor, led_current);   // set IR LED current
  VCNL4020_SetMode(&prox_sensor, MANUAL);           // get measurements on demand 
  delay(10);   
}

uint16_t proxCalibration(VCNL4020* pSensor)
{
  // Flush initial readings
  for (int i = 0; i < 3; i++) {
    prox = VCNL4020_ReadProximity(pSensor);
    delay(period);
  }

  // Perform calibration readings
  for (int i = 0; i < n_calib_samples; i++) {
    prox = VCNL4020_ReadProximity(pSensor);
    sum += prox;
    delay(period);
  }

  // Take average as background
  background = sum / n_calib_samples;
  return background;
}

// Read acceleration along X axis
float readAccelX() 
{
  // get acceleration readings (must set MSB to 1 to read consecutive registers)
  int16_t rawValue = i2cRead<int16_t>(ADDR_ACCEL, ACCEL_OUT_X | (1 << 7), 2); 
  rawValue = rawValue >> 6;  // remove lower 6 bits

  // convert to signed int, then convert to m/s^2 (normal mode = 3.9 milli-g per bit)
  return 3.9 * 9.8 / 1000 * rawValue;
}

// Read acceleration along Y axis
float readAccelY() 
{
  // get acceleration readings (must set MSB to 1 to read consecutive registers)
  int16_t rawValue = i2cRead<int16_t>(ADDR_ACCEL, ACCEL_OUT_Y | (1 << 7), 2); 
  rawValue = rawValue >> 6;  // remove lower 6 bits

  // convert to signed int, then convert to m/s^2 (normal mode = 3.9 milli-g per bit)
  return 3.9 * 9.8 / 1000 * rawValue;
}

// Place MCU in power-down mode
void goToSleep() 
{
  set_sleep_mode(SLEEP_MODE_PWR_DOWN); // Use power-down mode
  sleep_enable();
  sleep_mode();    // Go to sleep
  sleep_disable(); // Resume here after wake-up
}

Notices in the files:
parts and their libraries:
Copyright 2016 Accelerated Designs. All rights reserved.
